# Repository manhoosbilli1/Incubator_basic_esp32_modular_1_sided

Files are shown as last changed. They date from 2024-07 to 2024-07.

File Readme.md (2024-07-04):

# V#1.3 Incubator pcb for a client.

contains:
- esp32, 
- wifi and bluetooth capability. 
- works with mobile app
- lcd and encoder for menu navigation
- heater AC PWM and on/off support
- motor AC continuous and limit switch capability 
- fan
- humidifer
- aht20 (i2c Temp/humidity sensor)
- alternate connector for limit switches x2
- alternate connector heater pwm external ssr
- supposed to be delivered in a box with AC=DC convertor, jack, connection points board to box.
- App will be released soon that will report sensor data using firebase. 

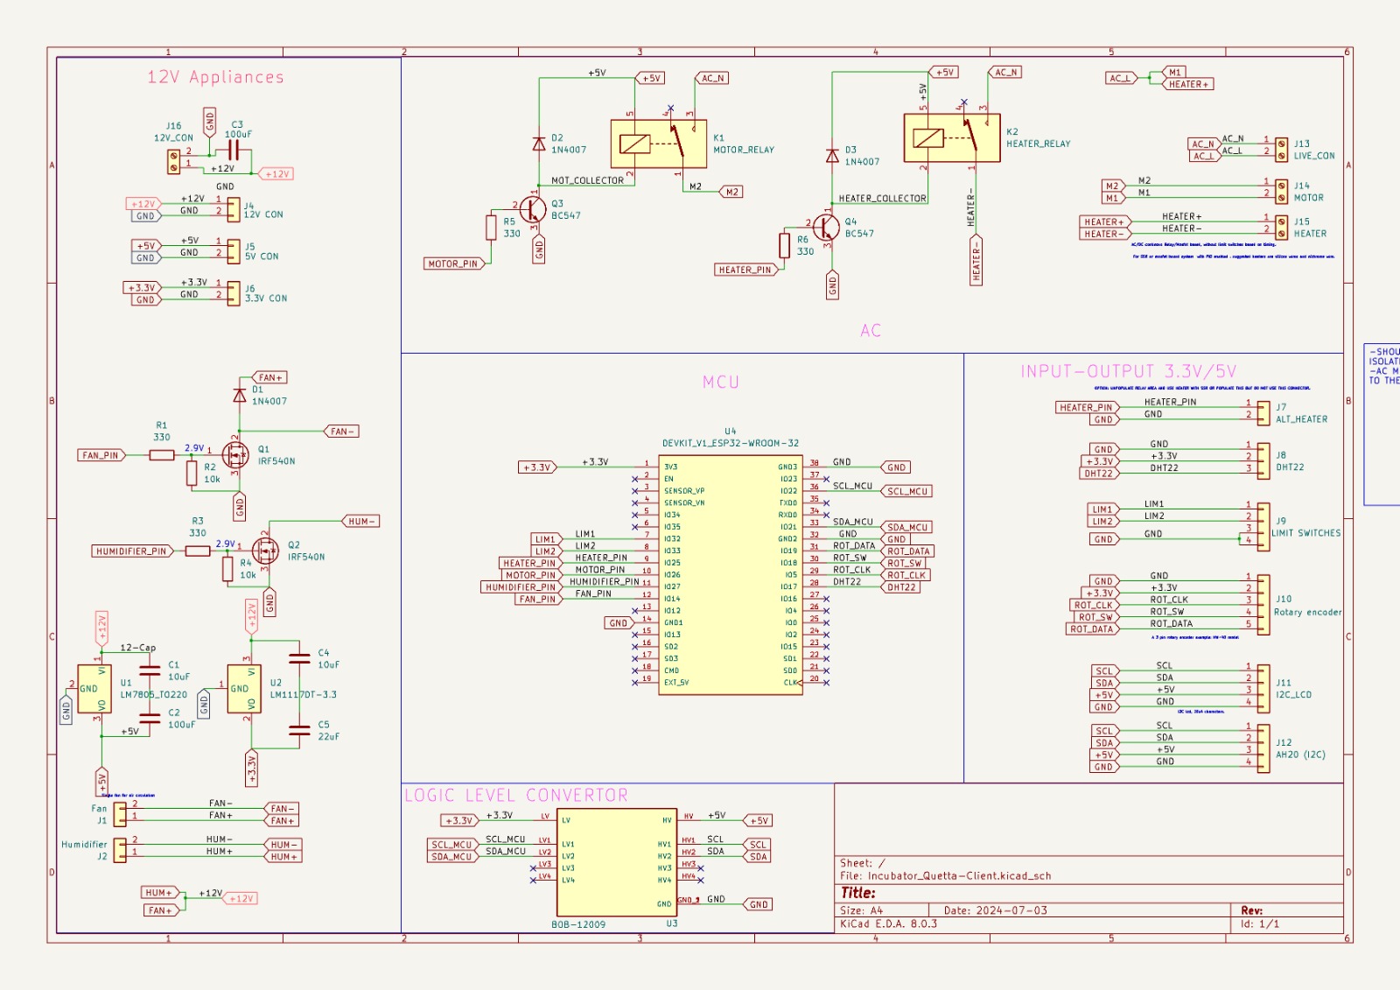
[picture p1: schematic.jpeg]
Schematic

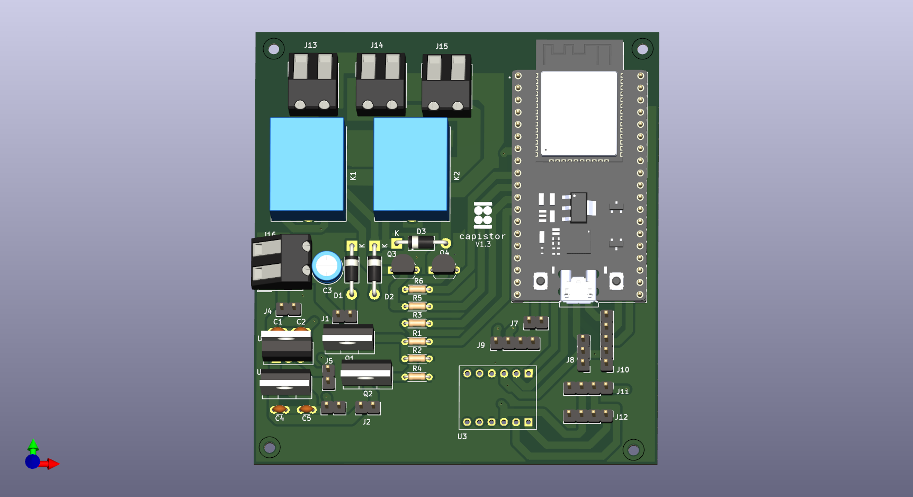
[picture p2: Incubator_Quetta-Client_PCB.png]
Build v1.3


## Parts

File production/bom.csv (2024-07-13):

Designator | Footprint | Quantity | Value | LCSC Part #
C1, C4 | C_Disc_D3.0mm_W1.6mm_P2.50mm | 2 | 10uF
C2 | C_Disc_D3.0mm_W1.6mm_P2.50mm | 1 | 100uF
C3 | C_Radial_D6.3mm_H5.0mm_P2.50mm | 1 | 100uF
C5 | C_Disc_D3.0mm_W1.6mm_P2.50mm | 1 | 22uF
D1, D2, D3 | D_DO-41_SOD81_P10.16mm_Horizontal | 3 | 1N4007
J1 | PinHeader_1x02_P2.54mm_Vertical | 1 | Fan
J10 | PinHeader_1x05_P2.54mm_Vertical | 1 | Rotary encoder
J11 | PinHeader_1x04_P2.54mm_Vertical | 1 | I2C_LCD
J12 | PinHeader_1x04_P2.54mm_Vertical | 1 | AH20 (I2C)
J13 | Altech_AK100_1x02_P5.00mm | 1 | LIVE_CON
J14 | Altech_AK100_1x02_P5.00mm | 1 | MOTOR
J15 | Altech_AK100_1x02_P5.00mm | 1 | HEATER
J16 | Altech_AK100_1x02_P5.00mm | 1 | 12V_CON
J2 | PinHeader_1x02_P2.54mm_Vertical | 1 | Humidifier
J4 | PinHeader_1x02_P2.54mm_Vertical | 1 | 12V CON
J5 | PinHeader_1x02_P2.54mm_Vertical | 1 | 5V CON
J6 | PinHeader_1x02_P2.54mm_Vertical | 1 | 3.3V CON
J7 | PinHeader_1x02_P2.54mm_Vertical | 1 | ALT_HEATER
J8 | PinHeader_1x03_P2.54mm_Vertical | 1 | DHT22
J9 | PinHeader_1x04_P2.54mm_Vertical | 1 | LIMIT SWITCHES
K1 | Relay_SPDT_SANYOU_SRD_Series_Form_C | 1 | MOTOR_RELAY
K2 | Relay_SPDT_SANYOU_SRD_Series_Form_C | 1 | HEATER_RELAY
Q1, Q2 | TO-220-3_Vertical | 2 | IRF540N
Q3, Q4 | TO-92_Inline_Wide | 2 | BC547
R1, R3, R5, R6 | R_Axial_DIN0204_L3.6mm_D1.6mm_P5.08mm_Horizontal | 4 | 330
R2, R4 | R_Axial_DIN0204_L3.6mm_D1.6mm_P5.08mm_Horizontal | 2 | 10k
U1 | TO-220-3_Vertical | 1 | LM7805
U2 | TO-220-3_Vertical | 1 | LM1117DT-3.3
U3 | CONV_BOB-12009 | 1 | BOB-12009
U4 | MODULE_DEVKIT_V1_ESP32-WROOM-32 | 1 | DEVKIT_V1_ESP32-WROOM-32

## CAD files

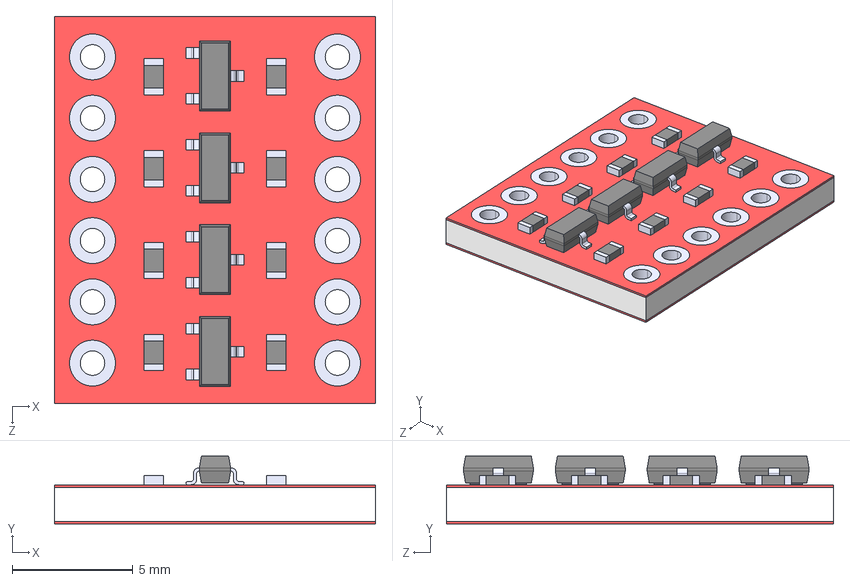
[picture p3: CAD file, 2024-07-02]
BOB-12009/BOB-12009.step
13.3 x 2.80 x 16.1 mm

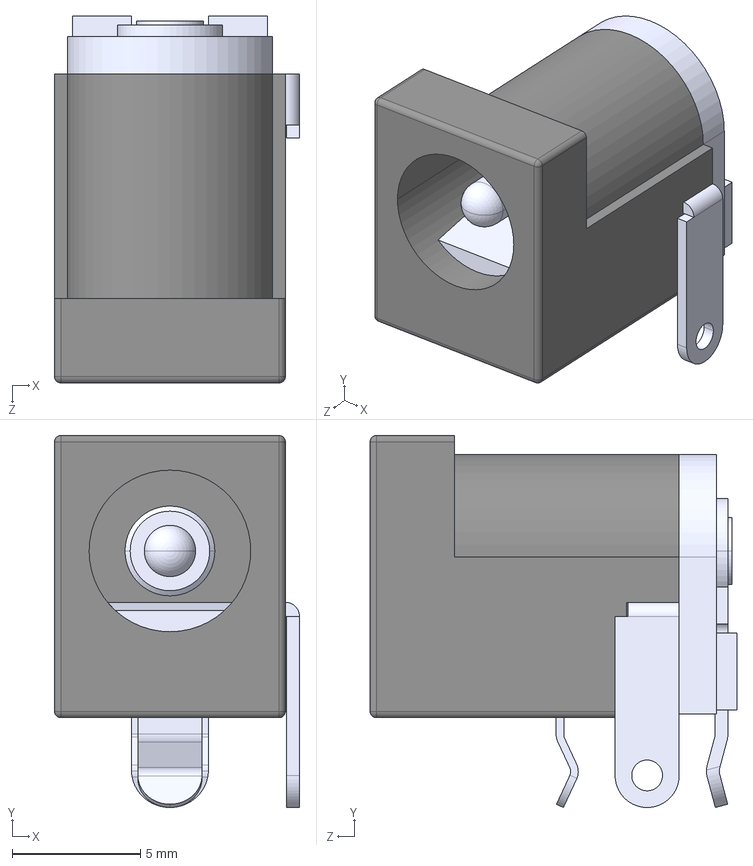
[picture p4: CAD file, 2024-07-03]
DCJ_200-10-A-xx-K_JACK/DCJ200-10-A-XX-K_REVA.step
9.55 x 14.5 x 14.3 mm

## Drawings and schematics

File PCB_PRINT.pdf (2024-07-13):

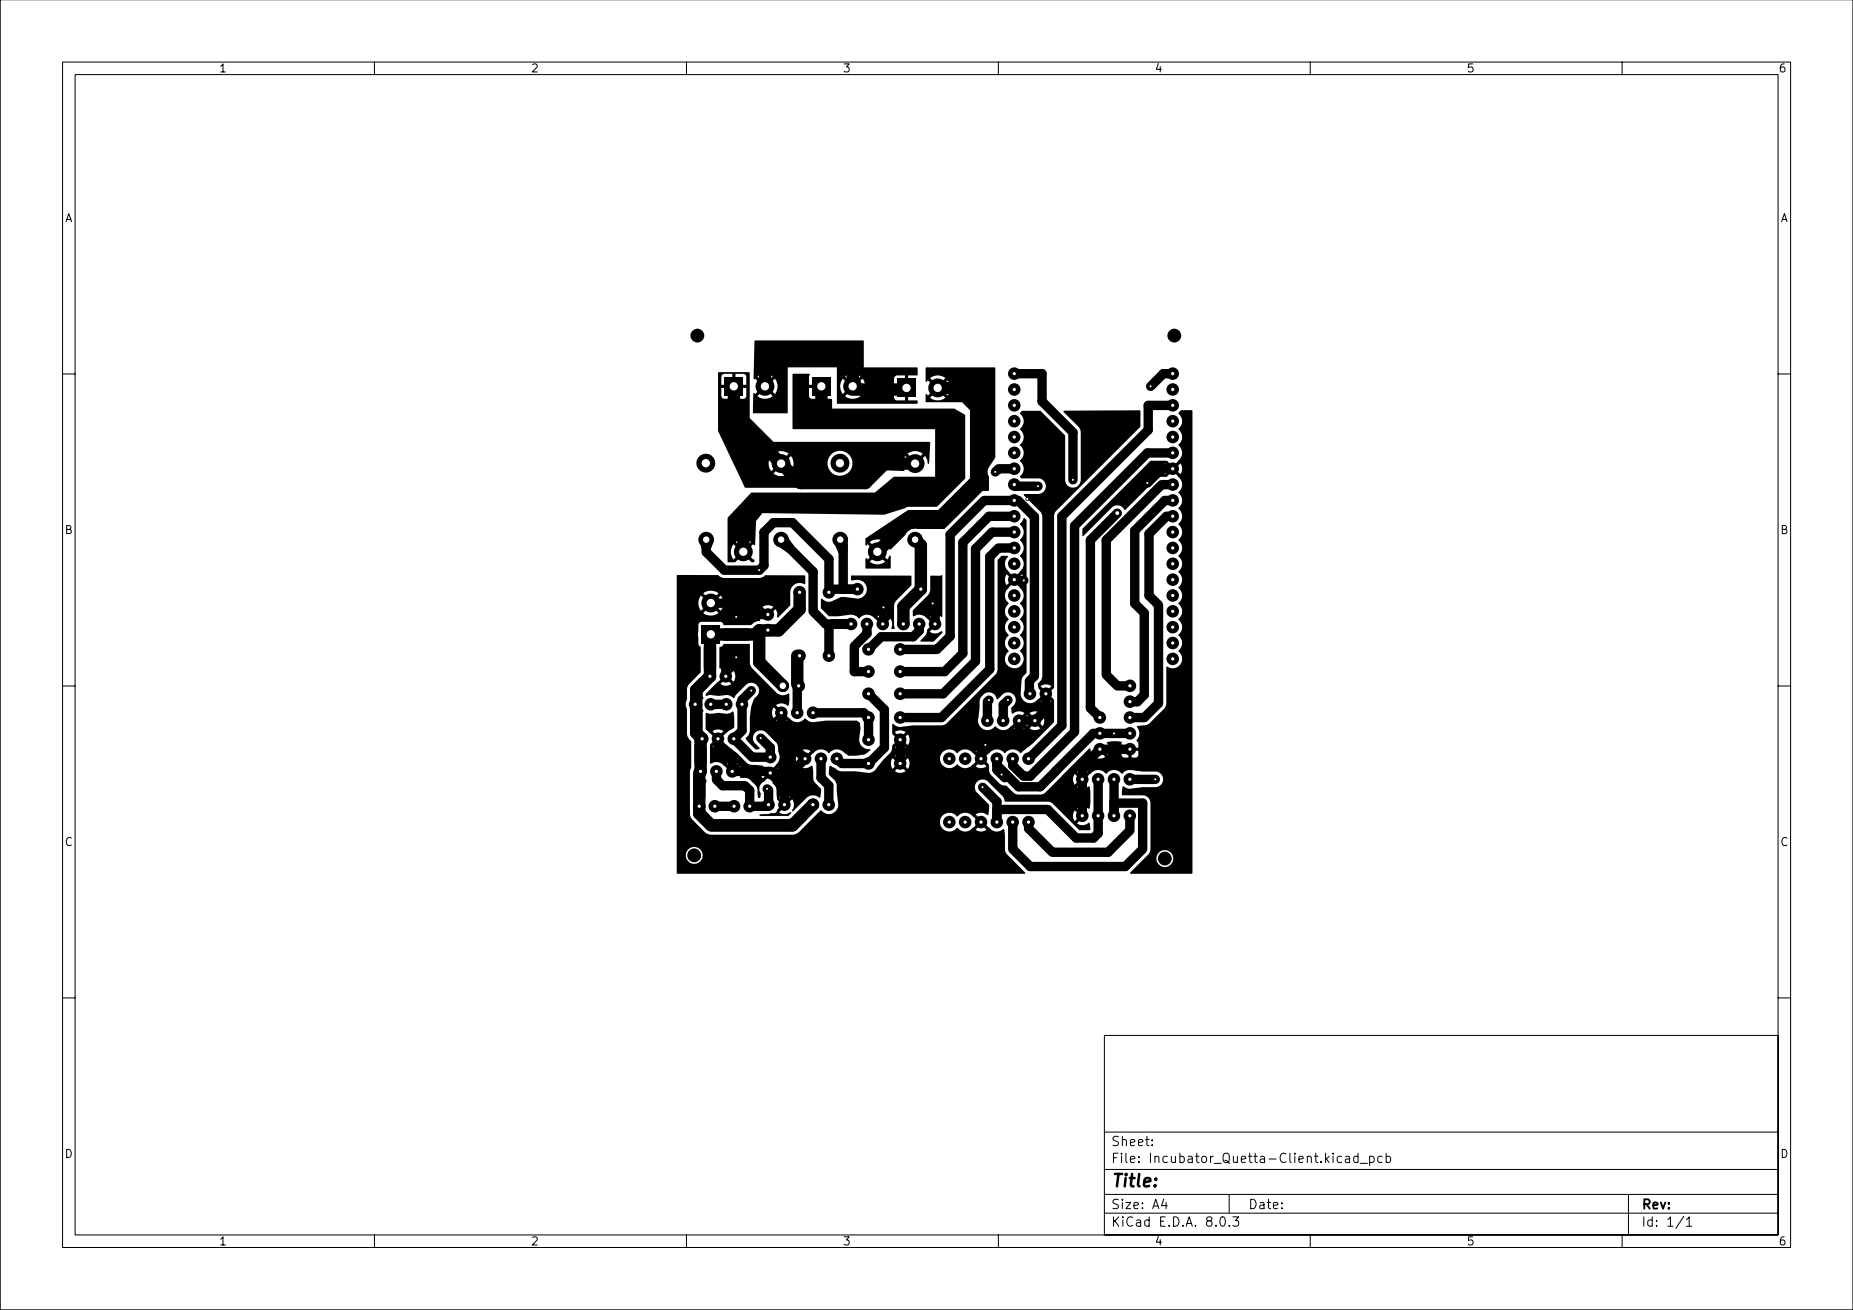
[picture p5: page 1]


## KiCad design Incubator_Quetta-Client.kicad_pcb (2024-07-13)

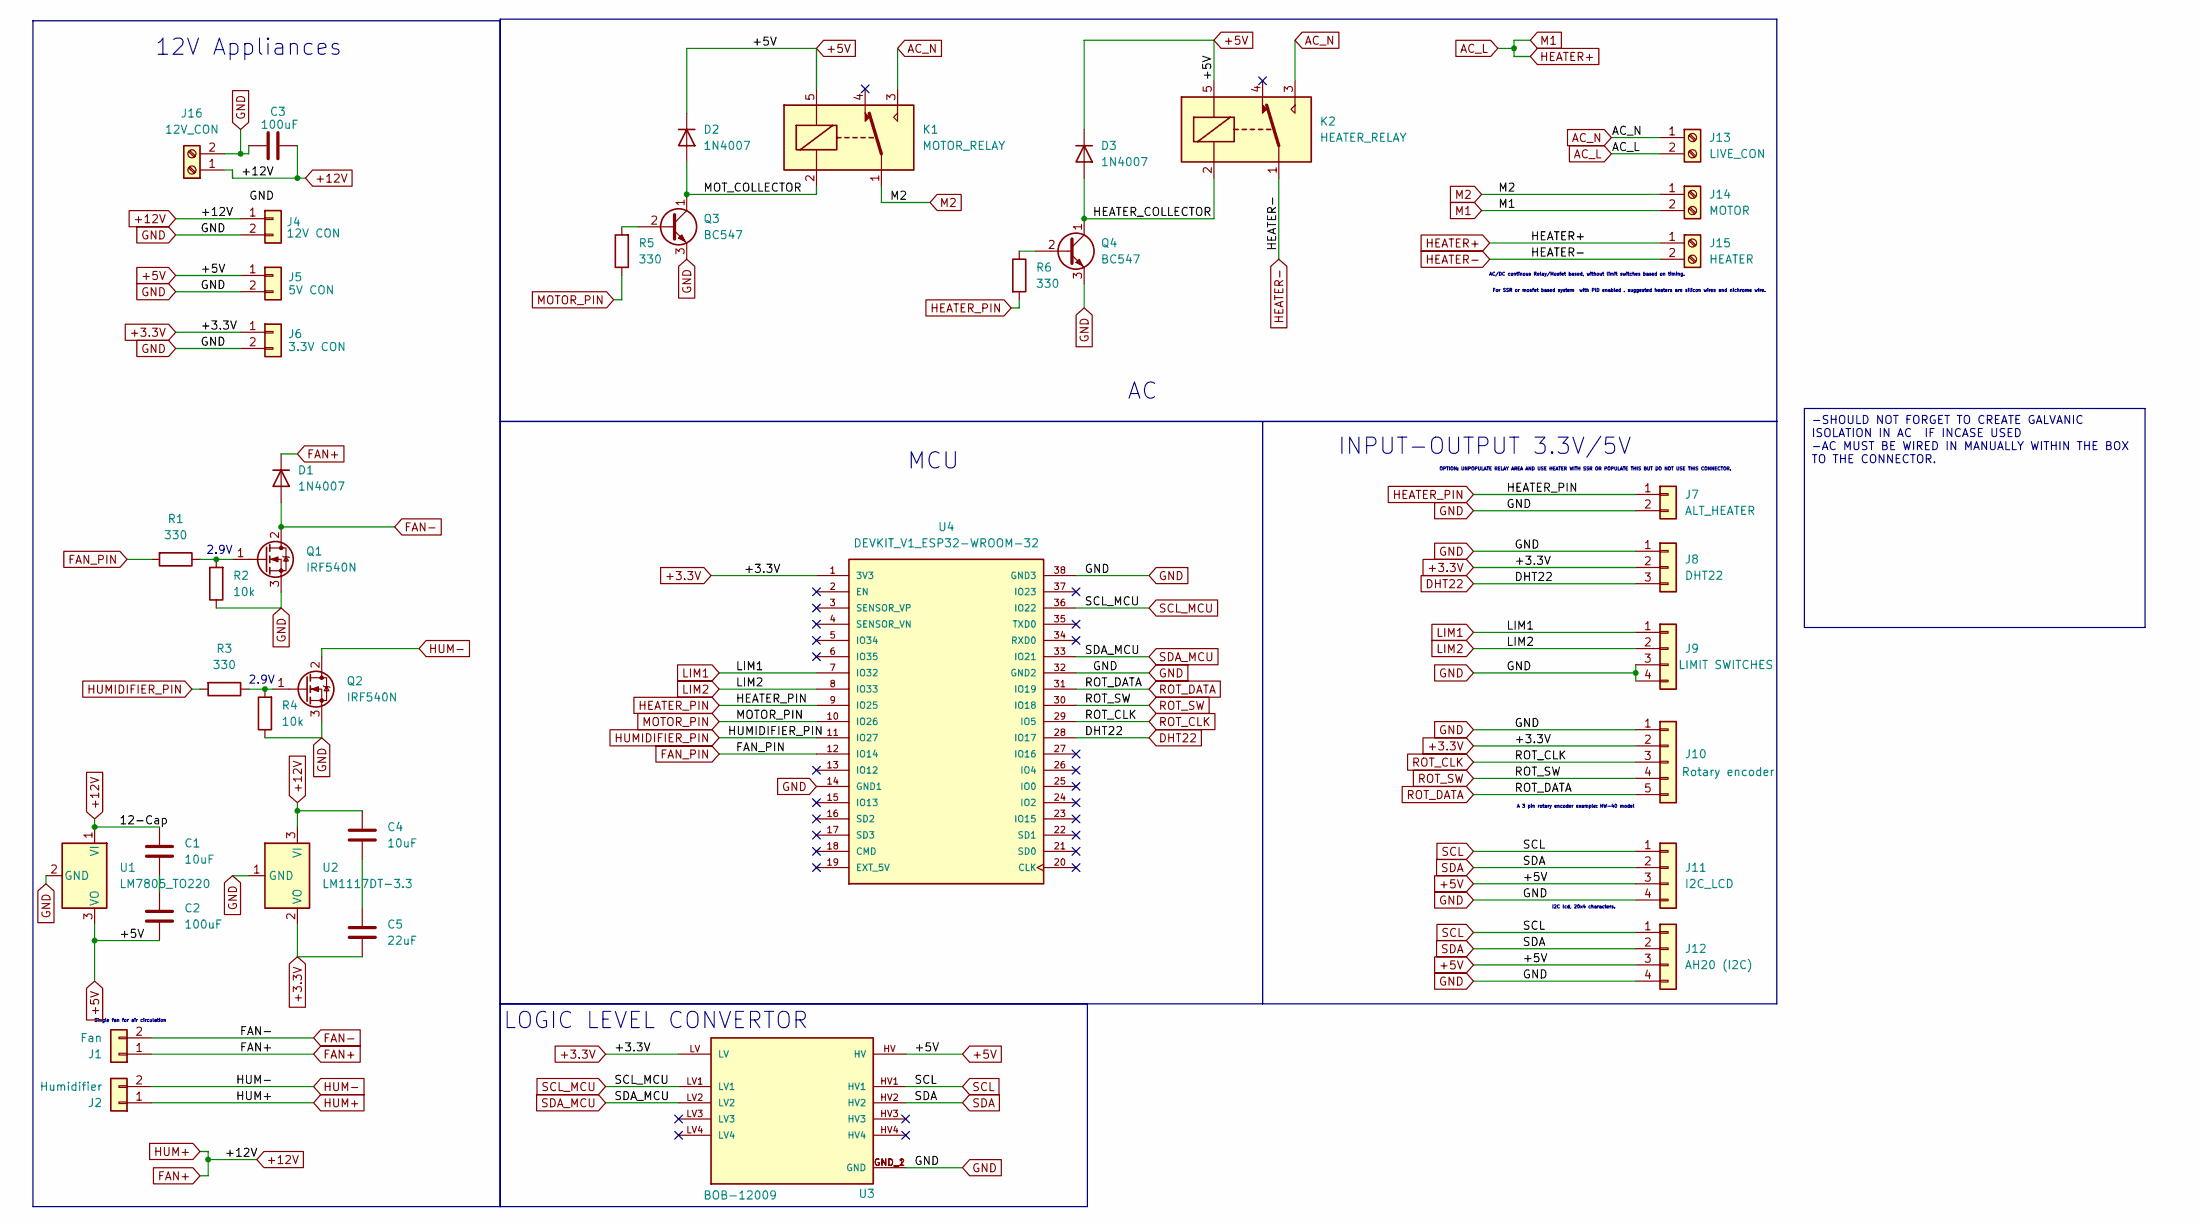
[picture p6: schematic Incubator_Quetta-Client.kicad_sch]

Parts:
C1, C4: 10uF; C_Disc_D3.0mm_W1.6mm_P2.50mm
C2: 100uF; C_Disc_D3.0mm_W1.6mm_P2.50mm
C3: 100uF; C_Radial_D6.3mm_H5.0mm_P2.50mm
C5: 22uF; C_Disc_D3.0mm_W1.6mm_P2.50mm
D1, D2, D3: 1N4007; D_DO-41_SOD81_P10.16mm_Horizontal
J1: Fan; PinHeader_1x02_P2.54mm_Horizontal
J2: Humidifier; PinHeader_1x02_P2.54mm_Horizontal
J4: 12V CON; PinHeader_1x02_P2.54mm_Vertical
J5: 5V CON; PinHeader_1x02_P2.54mm_Vertical
J6: 3.3V CON; PinHeader_1x02_P2.54mm_Vertical
J7: ALT_HEATER; PinHeader_1x02_P2.54mm_Vertical
J8: DHT22; PinHeader_1x03_P2.54mm_Vertical
J9: LIMIT SWITCHES; PinHeader_1x04_P2.54mm_Vertical
J10: Rotary encoder; PinHeader_1x05_P2.54mm_Vertical
J11: I2C_LCD; PinHeader_1x04_P2.54mm_Vertical
J12: AH20 (I2C); PinHeader_1x04_P2.54mm_Vertical
J13: LIVE_CON; Altech_AK100_1x02_P5.00mm
J14: MOTOR; Altech_AK100_1x02_P5.00mm
J15: HEATER; Altech_AK100_1x02_P5.00mm
J16: 12V_CON; Altech_AK100_1x02_P5.00mm
K1: MOTOR_RELAY; Relay_SPDT_SANYOU_SRD_Series_Form_C
K2: HEATER_RELAY; Relay_SPDT_SANYOU_SRD_Series_Form_C
Q1, Q2: IRF540N; TO-220-3_Vertical
Q3, Q4: BC547; TO-92_Inline
R1, R6: 330; R_Axial_DIN0204_L3.6mm_D1.6mm_P5.08mm_Horizontal
R2, R4: 10k; PinHeader_1x04_P2.54mm_Vertical
R3, R5: 330; PinHeader_1x04_P2.54mm_Vertical
U1: LM7805_TO220; TO-220-3_Vertical
U2: LM1117DT-3.3; TO-252-3_TabPin2
U3: BOB-12009; CONV_BOB-12009; PARTREV 01
U4: DEVKIT_V1_ESP32-WROOM-32; MODULE_ESP32_DEVKIT_V1; PARTREV N/A

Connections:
+3.3V: C5.2, J6.1, J8.2, J10.2, U2.2 (VO), U3.LV, U4.1 (3V3)
+5V: C2.2, D2.1 (K), D3.1 (K), J5.1, J11.3, J12.3, K1.5, K2.5, U1.3 (VO), U3.HV
+12V: C1.1, C3.2, C4.1, D1.1 (K), J1.1, J2.1, J4.1, J16.1, U1.1 (VI), U2.3 (VI)
/HEATER_COLLECTOR: D3.2 (A), K2.2, Q4.1 (C)
/MOT_COLLECTOR: D2.2 (A), K1.2, Q3.1 (C)
AC_L: J13.2, J14.2, J15.1
AC_N: J13.1, K1.3, K2.3
DHT22: J8.3, U4.28 (IO17)
FAN-: D1.2 (A), J1.2, Q1.2 (D)
FAN_PIN: R1.2, U4.12 (IO14)
GND: C3.1, J4.2, J5.2, J6.2, J7.2, J8.1, J9.3, J9.4, J10.1, J11.4, J12.4, J16.2, Q1.3 (S), Q2.3 (S), Q3.3 (E), Q4.3 (E), R2.1, R4.1, U1.2 (GND), U2.1 (GND), U3.GND_1 (GND), U3.GND_2 (GND), U4.14 (GND1), U4.32 (GND2), U4.38 (GND3)
HEATER-: J15.2, K2.1
HEATER_PIN: J7.1, R6.2, U4.9 (IO25)
HUM-: J2.2, Q2.2 (D)
HUMIDIFIER_PIN: R3.2, U4.11 (IO27)
LIM1: J9.1, U4.7 (IO32)
LIM2: J9.2, U4.8 (IO33)
M2: J14.1, K1.1
MOTOR_PIN: R5.1, U4.10 (IO26)
unnamed: C1.2, C2.1
unnamed: C4.2, C5.1
unnamed: Q1.1 (G), R1.1, R2.2
unnamed: Q2.1 (G), R3.1, R4.2
unnamed: Q3.2 (B), R5.2
unnamed: Q4.2 (B), R6.1
ROT_CLK: J10.3, U4.29 (IO5)
ROT_DATA: J10.5, U4.31 (IO19)
ROT_SW: J10.4, U4.30 (IO18)
SCL: J11.1, J12.1, U3.HV1
SCL_MCU: U3.LV1, U4.36 (IO22)
SDA: J11.2, J12.2, U3.HV2
SDA_MCU: U3.LV2, U4.33 (IO21)

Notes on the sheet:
-SHOULD NOT FORGET TO CREATE GALVANIC ISOLATION IN AC IF INCASE USED -AC MUST BE WIRED IN MANUALLY WITHIN THE BOX TO THE CONNECTOR.
I2C lcd, 20x4 characters.
AC/DC continous Relay/Mosfet based, without limit switches based on timing.
MCU
For SSR or mosfet based system with PID enabled . suggested heaters are silicon wires and nichrome wire.
OPTION: UNPOPULATE RELAY AREA AND USE HEATER WITH SSR OR POPULATE THIS BUT DO NOT USE THIS CONNECTOR.
INPUT-OUTPUT 3.3V/5V
12V Appliances
2.9V
LOGIC LEVEL CONVERTOR
A 3 pin rotary encoder example: HW-40 model
Single fan for air circulation

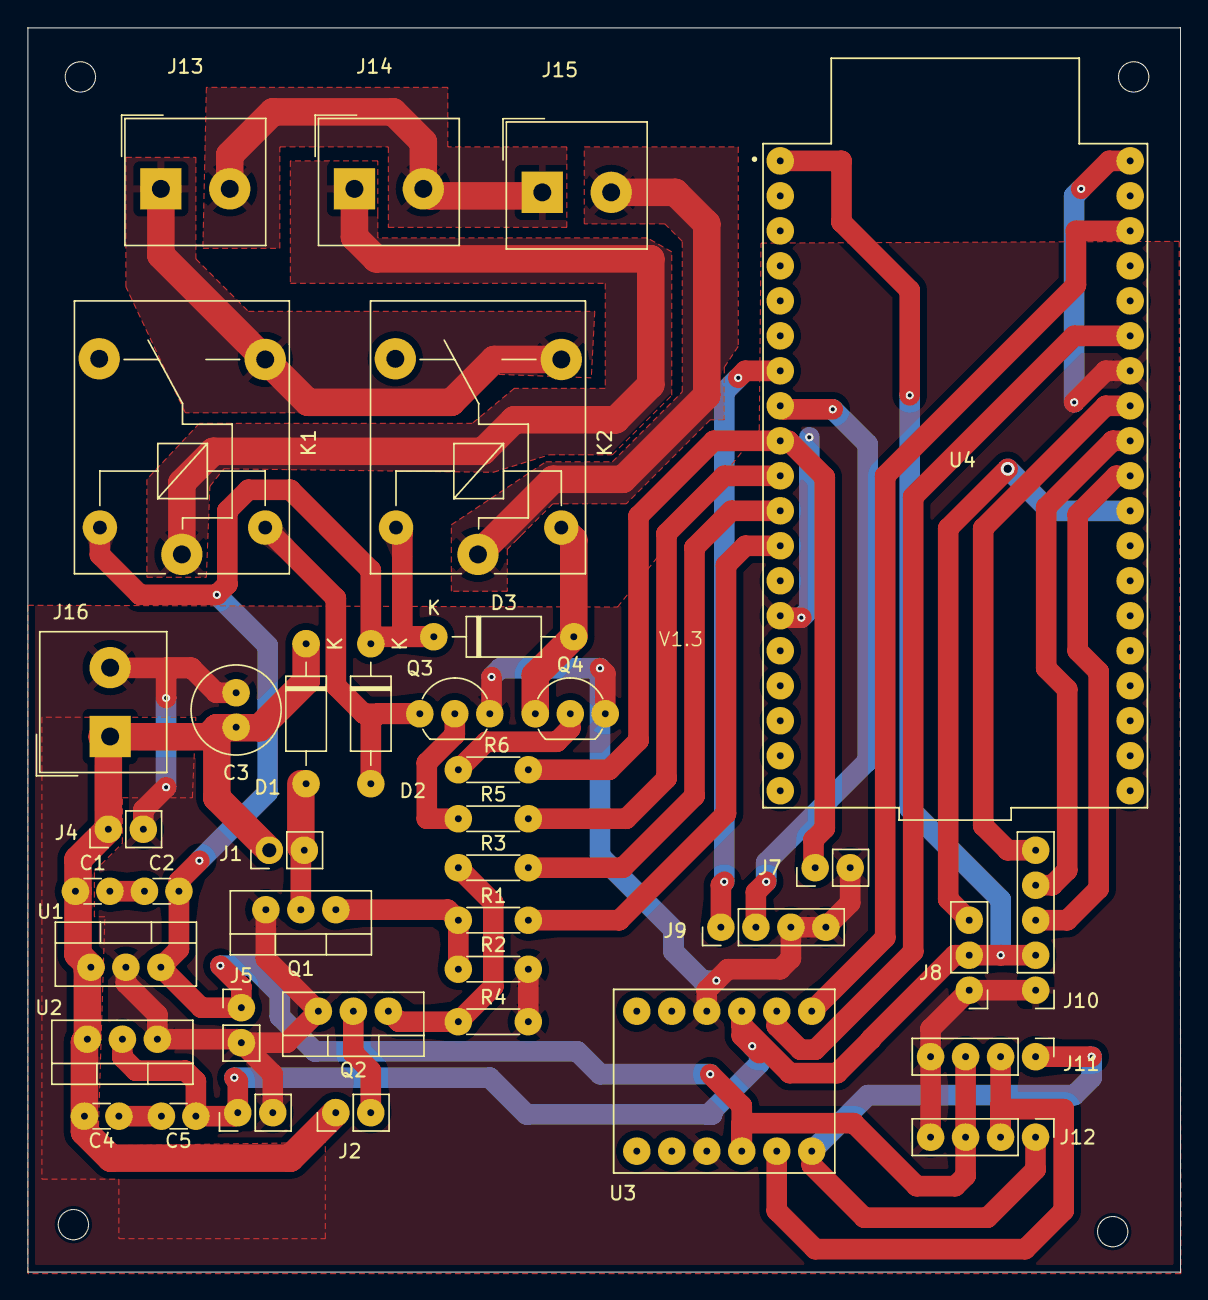
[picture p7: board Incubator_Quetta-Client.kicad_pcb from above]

Board: 2 copper layers, 83.7 x 90.3 mm, 39 parts (0 on the bottom side), 32 nets.

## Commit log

2024-07-02 basic schematic complete
    [BOB-12009.step, Incubator_Quetta-Client.kicad_pcb, Incubator_Quetta-Client.kicad_sch]
2024-07-03 basic layout done
    [BOB-12009.step, DCJ200-10-A-XX-K_REVA.step, Incubator_Quetta-Client.kicad_pcb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]
2024-07-04 finalised pcb. all done. waiting for approval
    [Incubator_Quetta-Client.kicad_pcb, Incubator_Quetta-Client.kicad_sch]
